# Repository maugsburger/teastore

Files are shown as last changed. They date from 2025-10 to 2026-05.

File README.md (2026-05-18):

# Teabag Dispenser

Organizes all your teabags in a nice dispenser with fully parametric dimensions,
mountable on the top or back

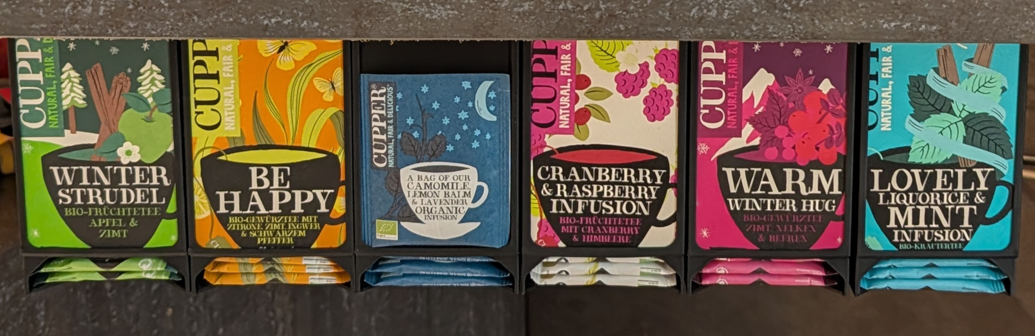
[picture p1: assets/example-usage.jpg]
Usage Example image)


## Usage

Open the `teabag.scad` in a recent (see below) OpenSCAD version.

### Parameters

Completely parametric design, you can adjust nearly all dimensions and parameters to create the version that fits your needs.

No sanity check is done, you can end up with too long features that overlap and make usage impossible.
If you want to fuck up, I'm not gonna stop you.

Examples:

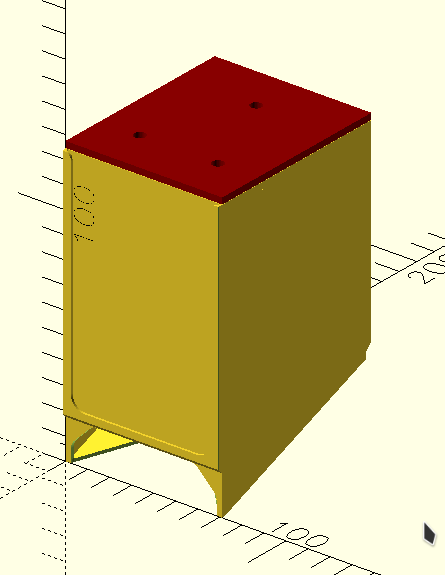
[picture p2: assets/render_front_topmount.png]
Front View, Top Mount enabled
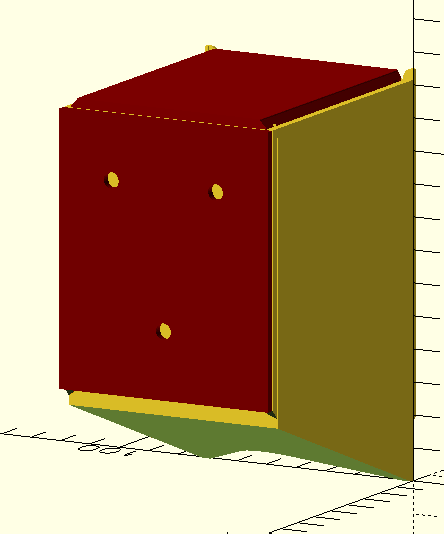
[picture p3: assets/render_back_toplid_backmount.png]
Back View, Back Mount and Lid enabled
|  |  |
| --- | --- |
| Rendered front view, with top mounting Lid and empty dovetail on the back | Rendered back view, with holder on the back and plain lid on the top. |

If you can't see the parameters, open the Customizer window at `OpenSCAD -> Window -> Customizer`

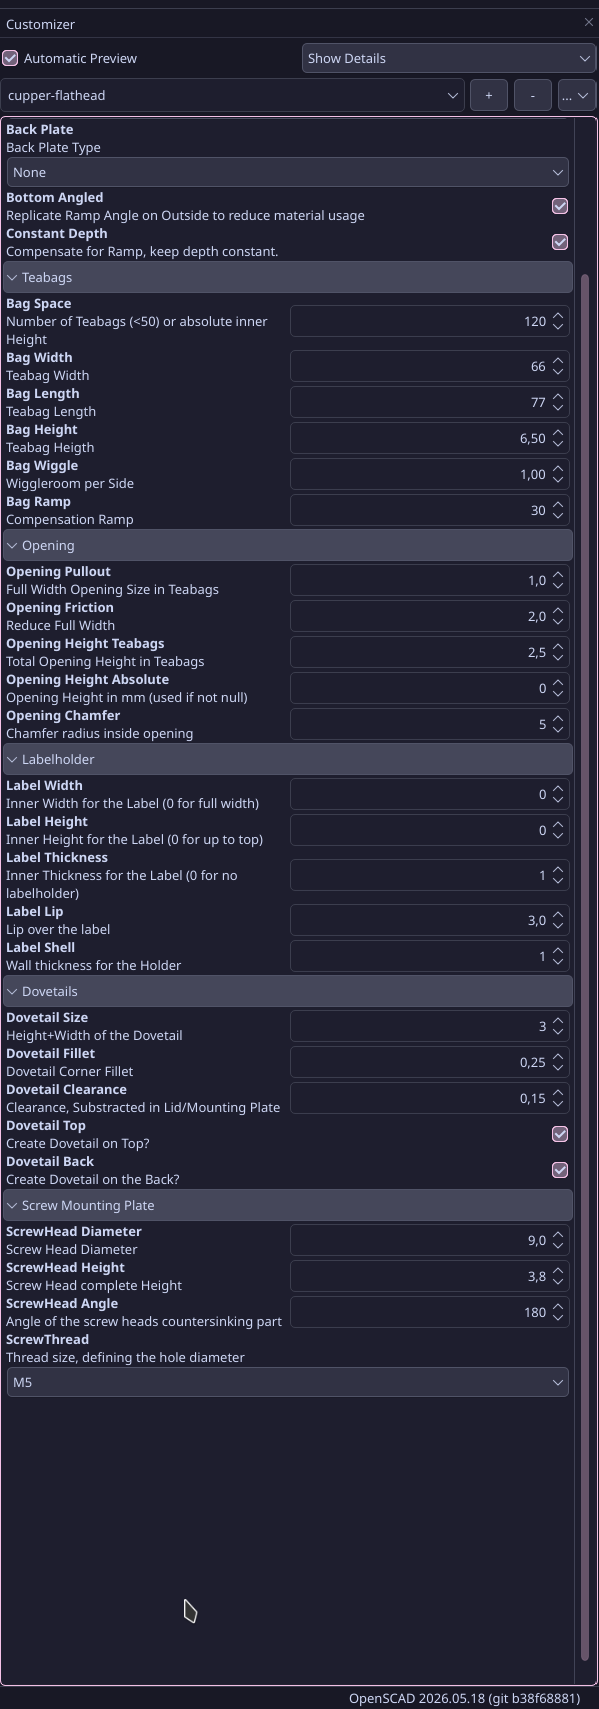
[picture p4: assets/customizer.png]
Options for Customization


## OpenSCAD

### Version

The current stable does not work. Use a [OpenSCAD development snapshot](https://openscad.org/downloads.html#snapshots) from at least October 2025.

### Settings
- Edit -> Preferences -> Advanced -> 3D Rendering -> Backend -> Manifold (New/Fast)

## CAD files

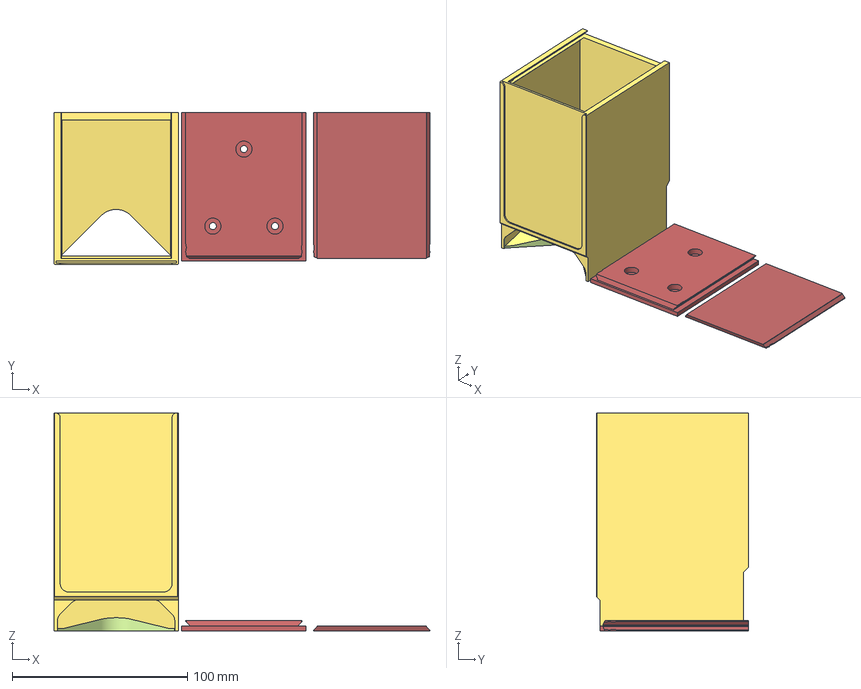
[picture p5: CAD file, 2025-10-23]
teabag.3mf
214.8 x 87.0 x 124.5 mm

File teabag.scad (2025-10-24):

include <openscad-screw-holes/screw_holes.scad> // https://github.com/nomike/openscad-screw-holes


/* [Global Options] */
// Main body thickness in mm
Shell_Thickness = 1.5; // 0.25

// Lay all parts flat onto bed
Print_Flat = true;

// Top Cover Type
Top_Cover="M"; // [N:None, L:Lid, M:MountingPlate ]
// Back Plate Type
Back_Plate="L"; // [N:None, L:Lid, M:MountingPlate ]

// Replicate Ramp Angle on Outside to reduce material usage
Bottom_Angled = true; 

// Compensate for Ramp, keep depth constant.
Constant_Depth = true;

/* [Teabags] */
// Number of Teabags (<50) or absolute inner Height
Bag_Space = 120;
// Teabag Width
Bag_Width = 66;
// Teabag Length
Bag_Length = 77;
// Teabag Heigth
Bag_Height = 6.5; // .25
// Wiggleroom per Side
Bag_Wiggle = 1.0;  // .25
// Compensation Ramp
Bag_Ramp = 20;

/* [Opening] */
// Full Width Opening Size in Teabags
Opening_Pullout = 1.0; // .1
// Reduce Full Width 
Opening_Friction = 1.0; // .1
// Total Opening Height in Teabags
Opening_Height_Teabags = 2.5; // .1
// Opening Height in mm (used if not null)
Opening_Height_Absolute = 0;
// Chamfer radius inside opening
Opening_Chamfer = 5;

/* [Labelholder] */
// Inner Width for the Label (0 for full width)
Label_Width = 0;
// Inner Height for the Label (0 for up to top)
Label_Height = 0;
// Inner Thickness for the Label (0 for no labelholder)
Label_Thickness = 1;
// Lip over the label
Label_Lip = 2.5; // .5
// Wall thickness for the Holder
Label_Shell = 1;

/* [Dovetails] */
// Height+Width of the Dovetail
Dovetail_Size = 3;
// Dovetail Corner Fillet
Dovetail_Fillet = 0.25; // 0.05
// Clearance, Substracted in Lid/Mounting Plate
Dovetail_Clearance = 0.15; // 0.05
// Create Dovetail on Top?
Dovetail_Top = true;
// Create Dovetail on the Back?
Dovetail_Back = true;

/* [Screw Mounting Plate] */
// Screw Head Diameter
ScrewHead_Diameter = 9; // 0.1
// Screw Head complete Height
ScrewHead_Height = 3.8; // 0.1
// Angle of the screw heads countersinking part
ScrewHead_Angle  = 180;
// Thread size, defining the hole diameter
ScrewThread = 5; // [ 0:M1.6, 1:M2, 2:M2.5, 3:M3, 4:M3.5, 5:M4, 6:M5 ]
// Extra Height of the Mounting Plate with Screwholes
ScrewPlateExtra = Dovetail_Size;


/* [Hidden] */
// quality
$fa = .2;
$fs = .1;
eps = 0.001;
// Calculations
screwhead = [ScrewHead_Diameter, ScrewHead_Height, ScrewHead_Angle];

// shell overall
sh_inner_x = Bag_Width + 2* Bag_Wiggle;
sh_inner_y = Bag_Length + 2* Bag_Wiggle;
sh_inner_z = Bag_Space < 50 ? Bag_Height * Bag_Space : Bag_Space;
sh_outer_x = sh_inner_x + 2* Shell_Thickness;
sh_outer_y = sh_inner_y + 2* Shell_Thickness; 
sh_outer_z = sh_inner_z + Shell_Thickness; // bottom layer with opening

echo("inner dimensions (front): W x D x H", sh_inner_x, sh_inner_y, sh_inner_z);
echo("outer dimensions (only base shell): W x D x H", sh_outer_x, sh_outer_y, sh_outer_z + Shell_Thickness);

// Shell pullout
sho_total_height =  Opening_Height_Absolute > 0  ?  Opening_Height_Absolute :  Opening_Height_Teabags * Bag_Height;

// Pullout part opening height 
sho_fullwidth_height = Opening_Pullout * Bag_Height;
// Offset for diagonal part above pullout part
sho_diagonal_height = sho_total_height - sho_fullwidth_height;

// ramp
ramp_angle = atan2(Bag_Ramp, sh_inner_y);

// helper modules 
module prism(l, w, h) {
    polyhedron(// pt      0        1        2        3        4        5
               points=[[0,0,0], [0,w,h], [l,w,h], [l,0,0], [0,w,0], [l,w,0]],
               // top sloping face (A)
               faces=[[0,1,2,3],
               // vertical rectangular face (B)
               [2,1,4,5],
               // bottom face (C)
               [0,3,5,4],
               // rear triangular face (D)
               [0,4,1],
               // front triangular face (E)
               [3,2,5]]
               );}




// Basic Shell holding the bags, without top and bottom
module shell_base() {
    linear_extrude(sh_inner_z, convexity = 2)
    difference() {
    square([sh_outer_x, sh_outer_y]);
    translate([Shell_Thickness, Shell_Thickness, 0]) 
    square([sh_inner_x, sh_inner_y]);
    }
}

// Pullout opening for basic shell
module shell_opening() {
    opening_width = sh_inner_x-Opening_Friction;

    translate(v = [Opening_Friction/2,0,0]) 
    offset(r=Opening_Chamfer)  offset(delta=-Opening_Chamfer)
    //offset(delta=2, chamfer=true) 
    polygon([
        [0,-Opening_Chamfer-Shell_Thickness],
        [0,0],
        [0,sho_fullwidth_height],
        [sho_diagonal_height,
            sho_fullwidth_height + sho_diagonal_height],
        [opening_width-sho_diagonal_height,
            sho_fullwidth_height + sho_diagonal_height],
        [opening_width,sho_fullwidth_height],
        [opening_width,0],
        [opening_width,-Opening_Chamfer-Shell_Thickness]
    ]);
    
}

module shell_bottom() {
    chamfer = 1;
    radius=12;

    ramp_height = sh_outer_y * tan(ramp_angle);
    prism_z_offset = Shell_Thickness * (1 - tan(ramp_angle));

    opening_width = sh_inner_x-Opening_Friction;

    difference() {

        union() {
            cube([sh_outer_x, sh_outer_y, Shell_Thickness+eps]);
            translate([0,0,prism_z_offset])
            prism(sh_outer_x, sh_outer_y, ramp_height);
        };

        translate([Shell_Thickness+Opening_Friction/2,chamfer,-1])
        linear_extrude(h=sh_inner_z) {
            // lower part / wide opening
            offset(r=chamfer) offset(delta=-chamfer)
            polygon([
                [0, -2*chamfer],
                [0, 0],
                [opening_width/2-radius, opening_width/2-radius],
                [opening_width/2+radius, opening_width/2-radius],
                [opening_width, 0],
                [opening_width, -2*chamfer]
            ]);
            
            // rounding in top
            difference() {
            offset(r=radius) offset(delta=-radius)
            polygon([
                [0, -2*radius],
                [0, 0],
                [opening_width/2, opening_width/2],
                [opening_width, 0],
                [opening_width, -2*radius]
            ]);
            polygon([
                [0, -2*radius-1],
                [0, 0],
                [opening_width, 0],
                [opening_width, -2*radius-1]
            ]);
            }
        }
    }
}

module bottom_cutoff() {
    // calculate angle of ramp

    // inner surface starts at [ 0, 0, prism_z_offset ]
    prism_z_offset = Shell_Thickness * (1 - tan(ramp_angle));
    // z distance to keep angled surfaces at perpendicular distance Shell_Thickness
    shell_thickness_angled = Shell_Thickness * cos(ramp_angle);
    // combine them for final z offset
    z_offset = prism_z_offset - shell_thickness_angled;
    
    echo("offset:", prism_z_offset, shell_thickness_angled, z_offset);

    y = sh_outer_y +  Dovetail_Size + eps;
    z = y * tan(ramp_angle);    

    translate(v = [-1, 0 ,z_offset]) 
    prism(sh_outer_x + 2, y, z);
}

module backfill() {
    // Constant_Depth

    // define dimension
    px = sh_inner_x + 2*eps;
    py = (sh_inner_y ) - (Bag_Length * cos(ramp_angle));
    pz = sh_inner_z - //sh_inner_y * tan(ramp_angle);
        ( Bag_Length * cos(ramp_angle) + Shell_Thickness ) * tan(ramp_angle) + Shell_Thickness;

    // define starting point
    ty = Bag_Length * cos(ramp_angle) + Shell_Thickness;
    tz = Bag_Length * sin(ramp_angle) + Shell_Thickness;
    

    translate( [Shell_Thickness-eps, ty, tz] ) 
    prism(px, py, pz);
}
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

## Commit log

2025-10-22 add angle/chamfer to vertical dovetail overhang
    [teabag.scad]
2025-10-22 rename print mode
    [teabag.scad]
2025-10-22 make screw holes properly centerd
    [teabag.scad]
2025-10-22 improve debugging
    [teabag.scad]
2025-10-22 verified screw and bag values
    [teabag.scad]
2025-10-22 sub-int resolution for some parameters
    [teabag.scad]
2025-10-22 ramp for bags in the bottom
    [teabag.scad]
2025-10-22 fix scope issues
    [teabag.scad]
2025-10-22 automatic label full height mode
    [teabag.scad]
2025-10-22 bottom shell bag ramp offset for thinner overall bottom
    [teabag.scad]
2025-10-23 Space for Bags can be used as count or absoulte height
    [teabag.scad]
2025-10-23 option for automatic label width calucaltion
    [teabag.scad]
2025-10-23 informational size output added
    [teabag.scad]
2025-10-23 cleanup dovetailplate calculations
    [teabag.scad]
2025-10-23 notch feature for better plate grip
    [teabag.scad]
2025-10-23 made labelholder optional
    [teabag.scad]
2025-10-23 add a little corner to the opening to hold the last bag in
    [teabag.scad]
2025-10-23 working version
    fits for cupper bags
    [teabag.3mf, teabag.scad]
2025-10-24 constant depth and bottom angle option
    Bottom Sheöö_Thickness should stay the same, but doesn't - some error I currently can't find…
    [teabag.scad]
